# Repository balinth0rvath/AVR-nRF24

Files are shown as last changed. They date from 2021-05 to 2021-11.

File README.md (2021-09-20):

# RF Communication Mesh
### What is This?
A sensor network consisting a server running on a Pi and several environmental sensors based on AVR MCU's. These things are communicating each other via RF and the sensors are planned to work through a season with one charge of a 3.6V battery.  

---

### Code Structure
|Description|Module|
|---|---|
|Custom nRF24L01 driver in my forked Linux repo located in nRF24L01driver branch|https://github.com/balinth0rvath/linux/tree/nRF24L01driver|
|Server app and unit tests|https://github.com/balinth0rvath/AVR-nRF24/tree/master/server|
|HW related stuff (Schematics, gerber files etc...)|https://github.com/balinth0rvath/AVR-nRF24/tree/master/nRF24-design|
|Firmware of a sensor module|https://github.com/balinth0rvath/AVR-nRF24/tree/master/AVR-nRF24|

---

### Server UML
<p float="left">  
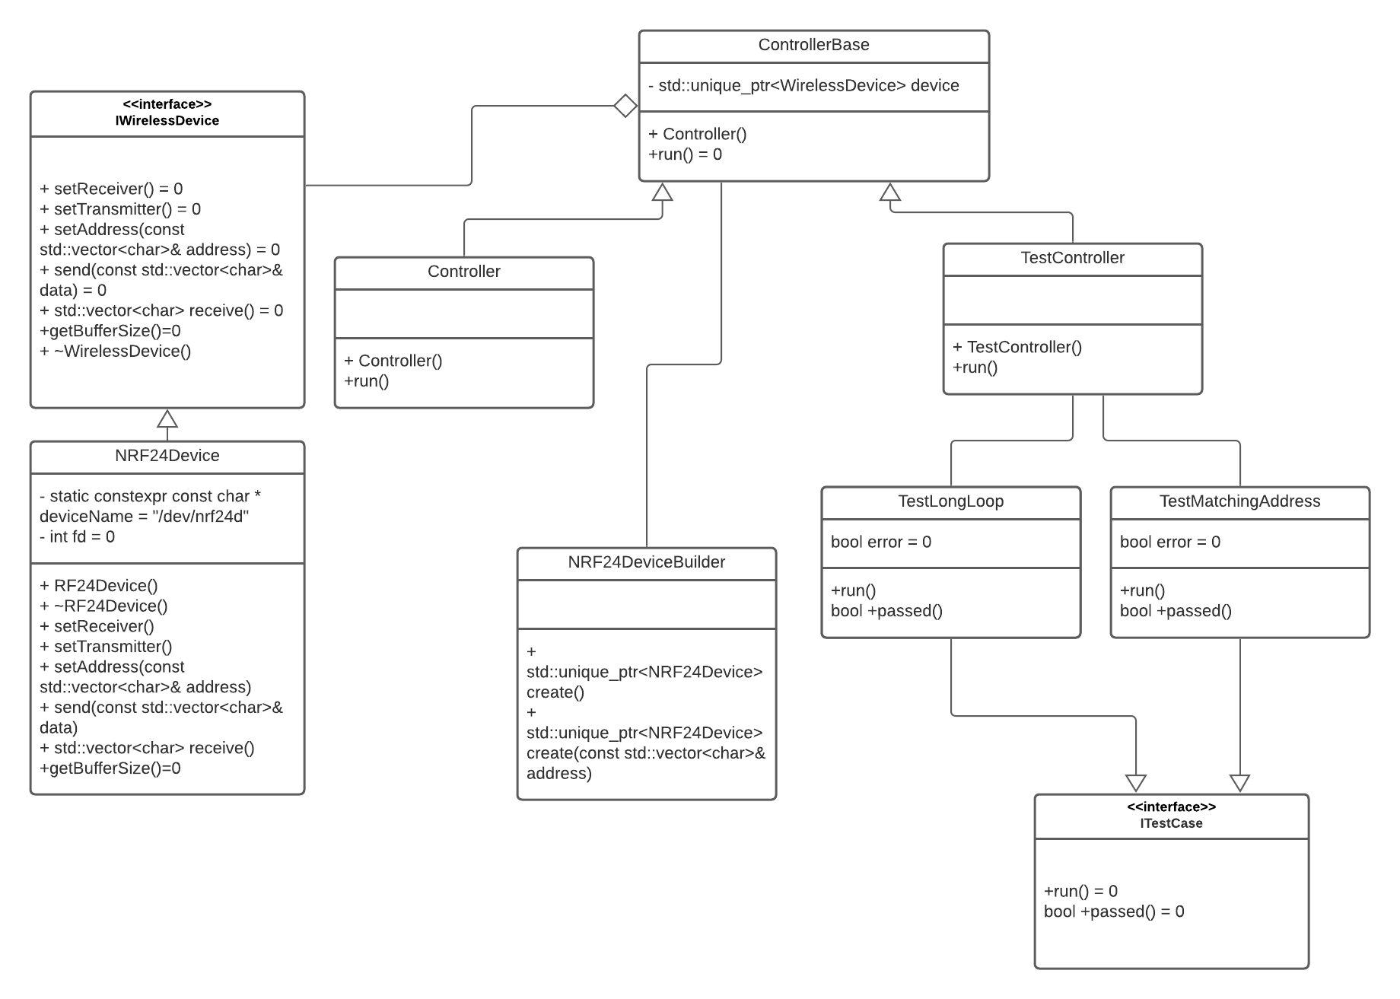
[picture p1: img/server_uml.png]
   
</p>

---

### Schematics
<p float="left">  
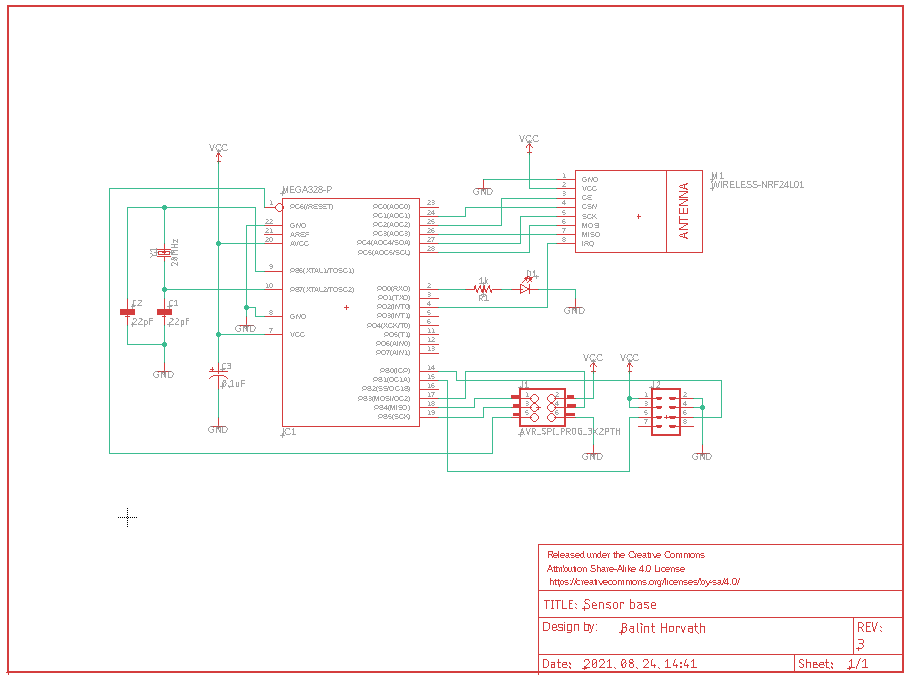
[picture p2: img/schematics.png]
   
</p>

---

### Current Dev Setup (Mid of September 2021)
<p float="left">  
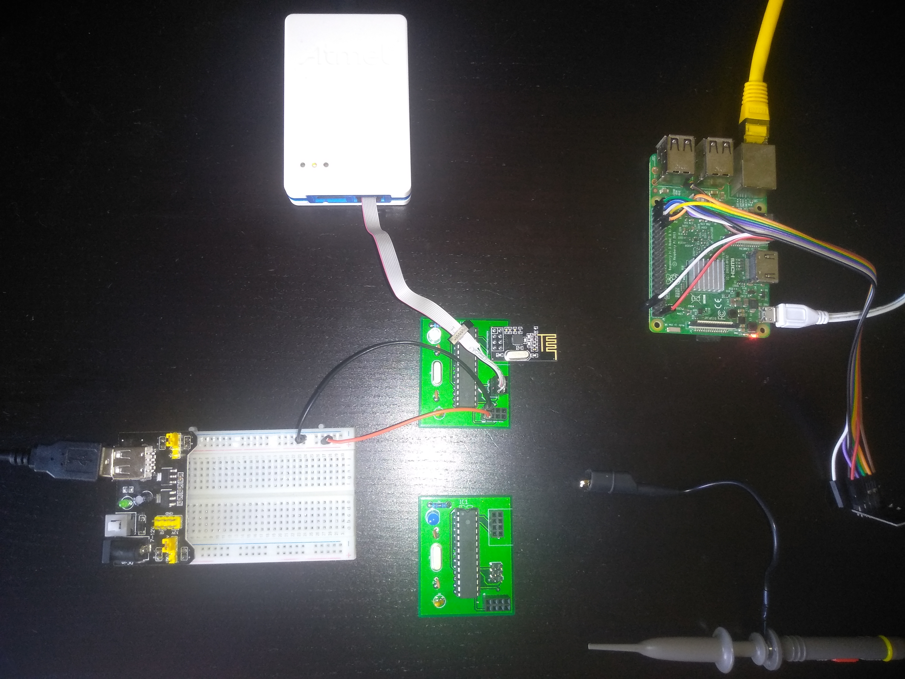
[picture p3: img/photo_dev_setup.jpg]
     
</p>

---

### Breadboard in Early Stage
<p float="left">  
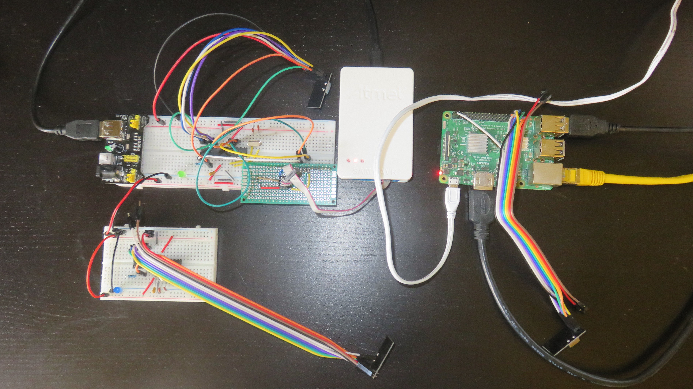
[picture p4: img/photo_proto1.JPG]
   
</p>

---

### First Prototypes without Sensors
<p float="left">  
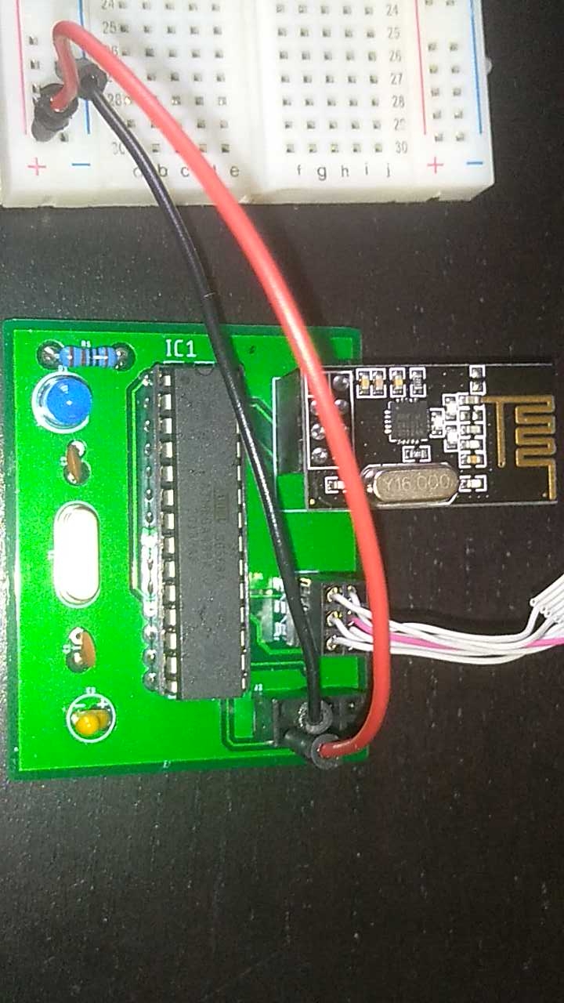
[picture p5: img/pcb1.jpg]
   
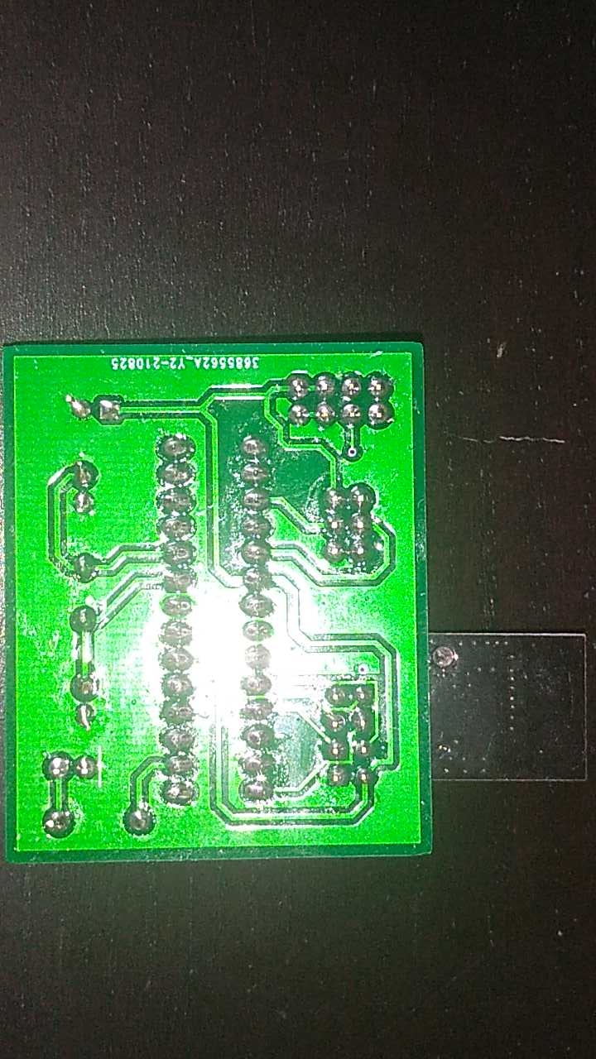
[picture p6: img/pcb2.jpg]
   
</p>

---

### Debug Screenshot, DS18B20 Sequence of Determining External Power Supply Mode
<p float="left">  
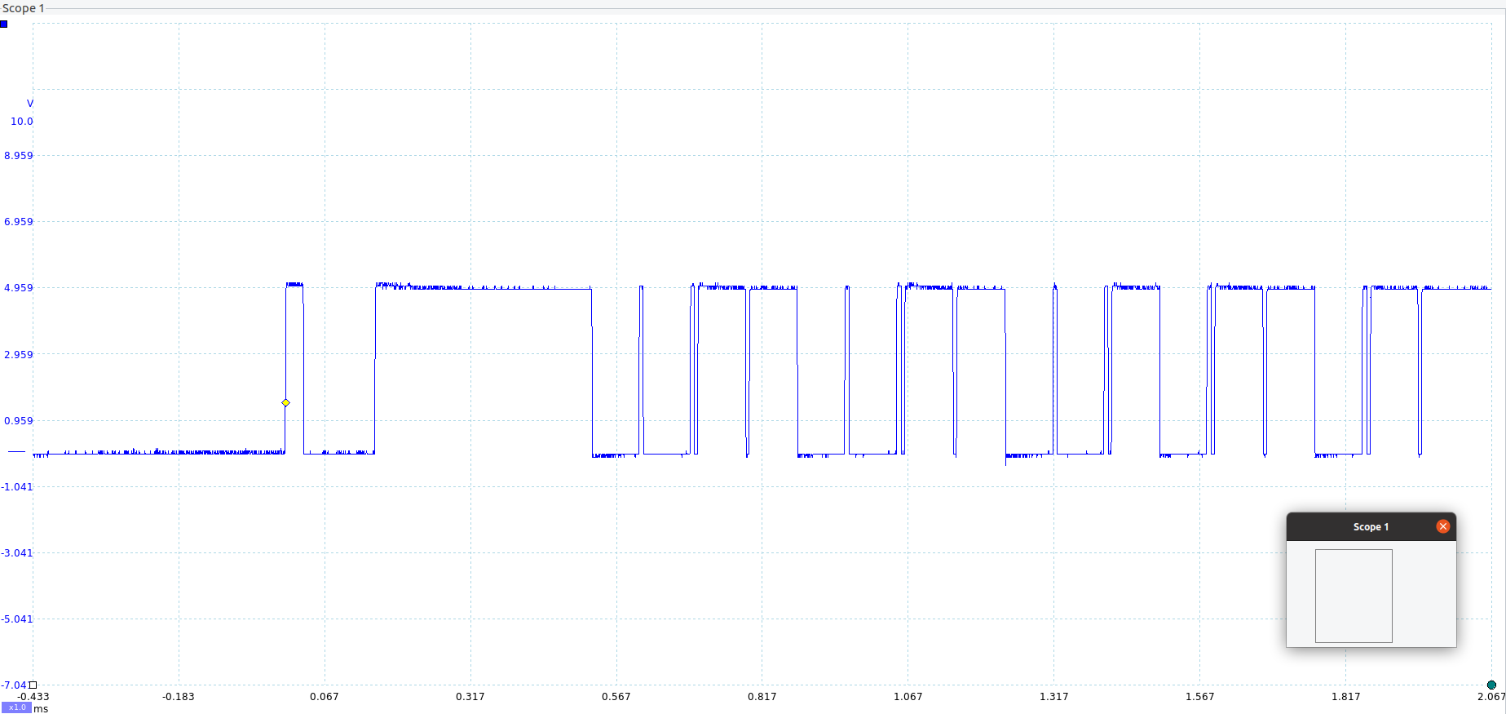
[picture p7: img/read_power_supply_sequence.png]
   
</p>

---
## Setup
### Init Yocto Build
```
$ mkdir rpi
$ cd rpi
$ git clone -b gatesgarth git://git.yoctoproject.org/poky.git
$ git clone -b gatesgarth git://git.openembedded.org/meta-openembedded
$ git clone -b gatesgarth git://git.openembedded.org/meta-raspberrypi
$ source poky/oe-init-build-env ./build
```
./build/conf/bblayers.conf
```
# POKY_BBLAYERS_CONF_VERSION is increased each time build/conf/bblayers.conf
# changes incompatibly
POKY_BBLAYERS_CONF_VERSION = "2" 

BBPATH = "${TOPDIR}"
BBFILES ?= ""

BBLAYERS ?= " \ 
  ~/yocto-builds/rpi/poky/meta \
  ~/yocto-builds/rpi/poky/meta-poky \
  ~/yocto-builds/rpi/poky/meta-yocto-bsp \
  ~/yocto-builds/rpi/meta-raspberrypi \
  ~/yocto-builds/rpi/meta-openembedded/meta-oe \
  ~/yocto-builds/rpi/meta-openembedded/meta-python \
  ~/yocto-builds/rpi/meta-openembedded/meta-networking \
  ~/yocto-builds/rpi/meta-openembedded/meta-multimedia \
  ~/yocto-builds/rpi/meta-openembedded/meta-filesystems \
  "
```

./build/conf/local.conf
```
...
MACHINE ??= "raspberrypi3"
...
DISTRO_FEATURES_append = "bluez5 bluetooth wifi systemd"
VIRTUAL-RUNTIME_init_manager = "systemd"
IMAGE_INSTALL_append = "crda iw bluez5 wpa-supplicant openssh"
```

### Create SD Card Image and SDK
```
$ cd rpi
$ . poky/oe-init-build-env
$ bitbake core-image-minimal
$ bitbake core-image-minimal -c populate_sdk
$ tmp/deploy/sdk/poky-glibc-x86_64-core-image-minimal-cortexa7t2hf-neon-vfpv4-raspberrypi3-toolchain-3.2.2.sh
```

### Install Packages
```
$ sudo apt-get install libssl-dev
```

### Build Kernel
```
$ cd <linux source root>
$ . /opt/poky/3.2.2/environment-setup-cortexa7t2hf-neon-vfpv4-poky-linux-gnueabi 
$ KERNEL=kernel7
$ make ARCH=arm CROSS_COMPILE=arm-poky-linux-gnueabi- bcm2709_defconfig
$ make ARCH=arm CROSS_COMPILE=arm-poky-linux-gnueabi- zImage modules dtbs
```

### Build Driver
```
$ cd <linux source root>
$ . /opt/poky/3.2.2/environment-setup-cortexa7t2hf-neon-vfpv4-poky-linux-gnueabi 
$ make ARCH=arm CROSS_COMPILE=arm-poky-linux-gnueabi- -C . M=drivers/char/nrf24/
$ scp nrf24.ko root@<IP of PI>:/home/root/.
```

### Server Setup
```
$ cd server
$ . /opt/poky/3.2.2/environment-setup-cortexa7t2hf-neon-vfpv4-poky-linux-gnueabi
$ make lib/libwireless.a
$ make
$ make test
$ scp server root@<IP of PI>:/home/root/.
$ scp test root@<IP of PI>:/home/root/.
```

### Server Init
```
$ insmod nrf24.ko
$ ./test
$ ./server
```

---

## Remote Debug Server
Target
```
$ gdbserver :1234 server
```
Host
```
$ arm-poky-linux-gnueabi-gdb server
(gdb) target remote <IP of PI>:1234
```
---

## Release Commits (Test Longloop)
A test named Test Longloop must pass in all release commits.
|Releas Date|Driver Branch and Commit Hash<br>Firmware and Design Branch and Commit Hash|
|----|---|
|20210517|linux@nRF24L01driver:8a4c0cdf7803df328cc4730b5077f52fee5dc932<br>AVR-nRF24@master:3eb939d17d8ff22d65403e109d810f7f85f86c85|
|20210523|linux@nRF24L01driver:8a4c0cdf7803df328cc4730b5077f52fee5dc932<br>AVR-nRF24@master:7b25dc61fc849677e8bb6358456cee5dc74c7301|
|20210531|linux@nRF24L01driver:7c86b9ca6b2d7ad1549c76c9caeeb97bab567bfb<br>AVR-nRF24@master:dd0c3b836620fbdc131a8c8d285148fa6ca5f2e6|
|20210820|inux@nRF24L01driver:7c86b9ca6b2d7ad1549c76c9caeeb97bab567bfb<br>AVR-nRF24@master:85c61a1c3e08124cf29ecca4751b73a7c155e9e8|
|20210909|linux@nRF24L01driver:f5a8eb844164f856415a3b459346a1253c0f87ff<br>AVR-nRF24@master:ca4479ed1e2c967fedf4eaf3a40d907f1cda15d0|
|20210919|linux@nRF24L01driver:f5a8eb844164f856415a3b459346a1253c0f87ff<br>AVR-nRF24@master:d2804b9a1e1fc83868c6ceb204d5eec31b9cb42f|

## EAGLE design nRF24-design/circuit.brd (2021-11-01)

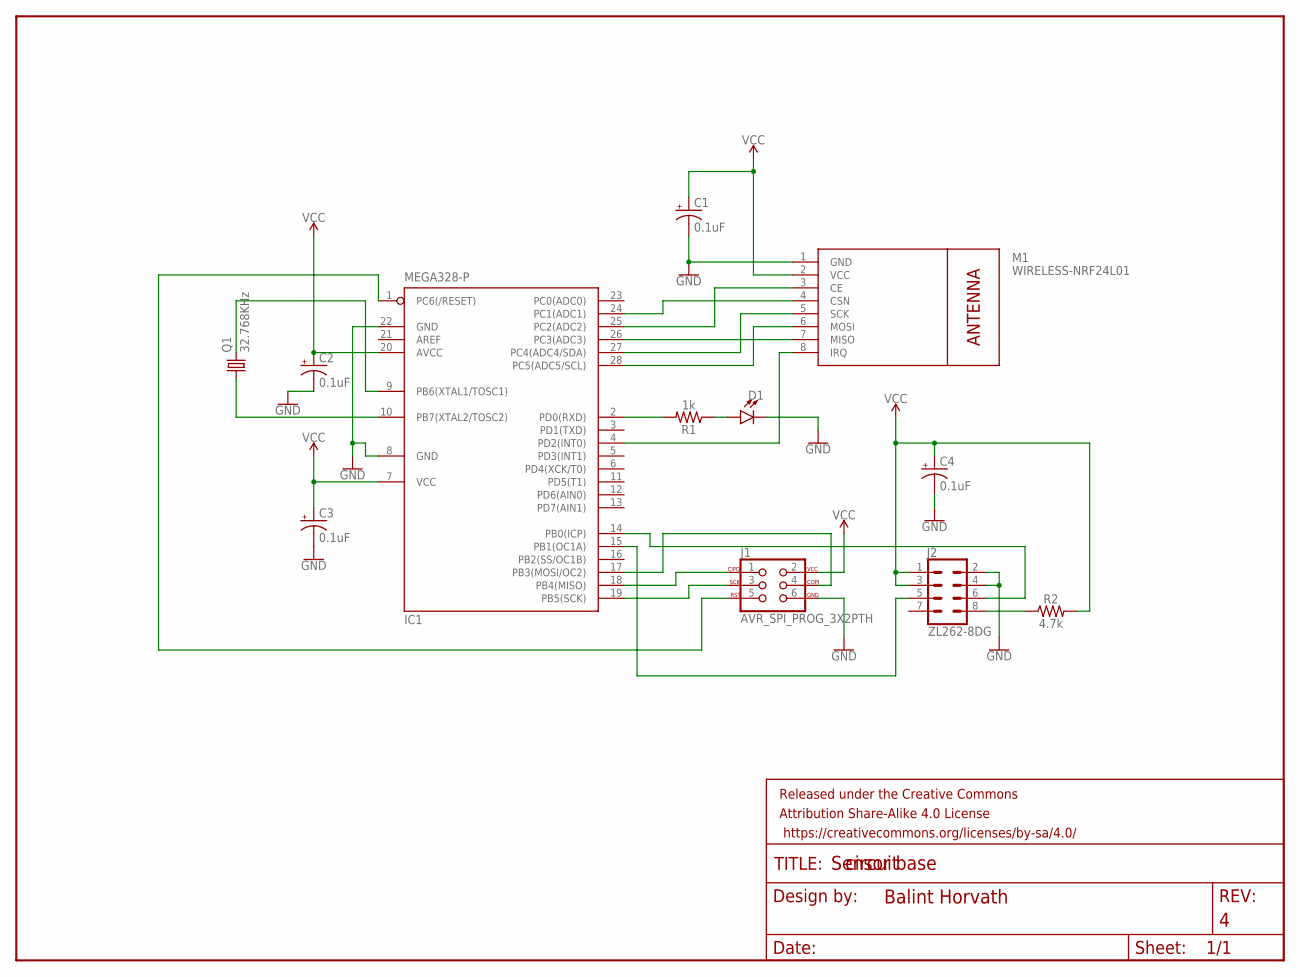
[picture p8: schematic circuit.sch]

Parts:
C1, C2, C3, C4: 0.1uF; CPOL-RADIAL-2.5MM-5MM
D1: LED5MM; LED_5MM
FRAME1: FRAME-LETTER; CREATIVE_COMMONS
IC1: MEGA328-P; DIL28-3
J1: AVR_SPI_PROG_3X2PTH; 2X3
J2: ZL262-8DG; 2X4
M1: WIRELESS-NRF24L01
Q1: 32.768KHz; TC26V
R1: 1k; AXIAL-0.3
R2: 4.7k; AXIAL-0.3

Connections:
GND: C1.2 (-), C2.2 (-), C3.2 (-), C4.2 (-), D1.K (C), IC1.8 (GND), IC1.22 (GND), J1.6, J2.2, J2.4, M1.1 (GND)
unnamed: IC1.9 (PB6(XTAL1/TOSC1)), Q1.2
unnamed: IC1.10 (PB7(XTAL2/TOSC2)), Q1.1
unnamed: IC1.2 (PD0(RXD)), R1.P$2 (2)
unnamed: D1.A, R1.P$1 (1)
unnamed: IC1.27 (PC4(ADC4/SDA)), M1.5 (SCK)
unnamed: IC1.4 (PD2(INT0)), M1.8 (IRQ)
unnamed: IC1.24 (PC1(ADC1)), M1.4 (CSN)
unnamed: IC1.26 (PC3(ADC3)), M1.7 (MISO)
unnamed: IC1.25 (PC2(ADC2)), M1.3 (CE)
unnamed: IC1.28 (PC5(ADC5/SCL)), M1.6 (MOSI)
unnamed: IC1.19 (PB5(SCK)), J1.3
unnamed: IC1.18 (PB4(MISO)), J1.1
unnamed: IC1.1 (PC6(/RESET)), J1.5
unnamed: IC1.17 (PB3(MOSI/OC2)), J1.4
unnamed: IC1.15 (PB1(OC1A)), J2.5
unnamed: J2.8, R2.P$1 (1)
unnamed: IC1.14 (PB0(ICP)), J2.6
VCC: C1.1 (+), C2.1 (+), C3.1 (+), C4.1 (+), IC1.7 (VCC), IC1.20 (AVCC), J1.2, J2.1, J2.3, M1.2 (VCC), R2.P$2 (2)

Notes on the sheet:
Sensor base

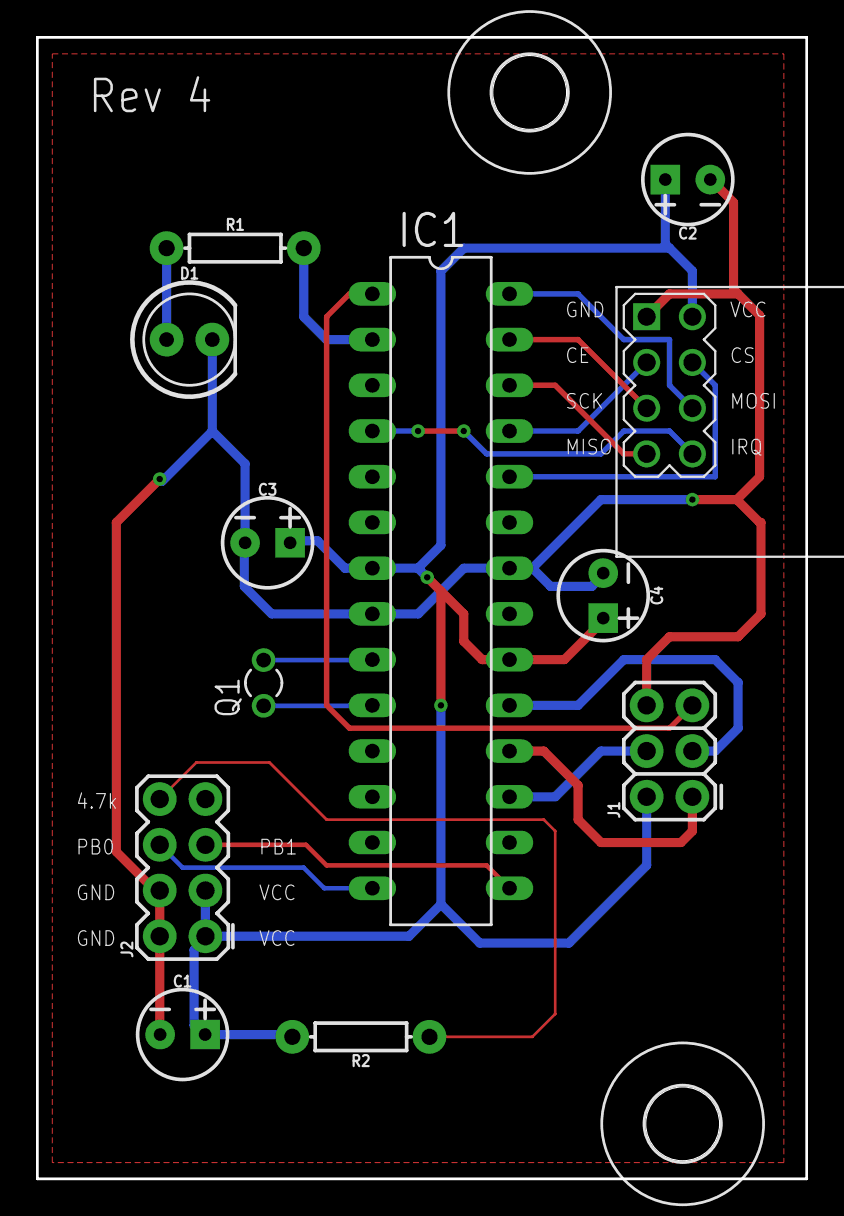
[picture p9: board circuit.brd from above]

Board: 2 copper layers, 42.7 x 63.4 mm, 15 parts (0 on the bottom side), 19 nets.

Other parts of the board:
U$1, U$2: 4,1

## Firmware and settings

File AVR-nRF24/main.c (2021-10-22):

/*
 * AVR-nRF24.c
 *
 * Created: 4/30/2021 3:04:23 PM
 *
 * author: balinth0rvath 
 */ 

 #define INIT_SETUP
 #undef TEST_BLINK 
 #undef TEST_ONE_PACKET 
 #undef TEST_LONGLOOP
 #undef TEST_SENSOR
 #undef TEST_SLEEP
 #define TEST_TIMER

#include "common.h"
#include <avr/io.h>
#include <util/delay.h>
#include <avr/interrupt.h>
#include <avr/sleep.h>
#include "nrf24.h"
#include "ds18b20.h"

void send_response(char* payload);

void send_response_with_head(void)
{					
	char payload[4] = {};
	nrf24_payload_buffer_item_t p;
	nrf24_get_buffer_head(&p);
	payload[0] = p.id;
	payload[1] = p.source_address;
	payload[2] = p.value;
	payload[3] = p.aux;
	send_response(payload);
	
}

void send_response_with_temperature(void)
{  
  char payload[4] = {};
  payload[0] = 0;
  payload[1] = 0;
  payload[2] = ds18b20_read_temperature() >> 4;
  payload[3] = 0;
  send_response(payload);
  
}

void send_response(char* payload)
{
  uint8_t status;
  nrf24_transmit_packet(payload, &status);
  _delay_ms(100);
  
  nrf24_transmit_packet(payload, &status);
  _delay_ms(100);
  
}

void send_dummy_packet(void)
{	
	uint8_t status;			
	char payload[4] = {};
	payload[0] = 54;
	payload[1] = 55;
	payload[2] = 53;
	payload[3] = 54;
	nrf24_transmit_packet(payload, &status);	
	_delay_ms(100);	
		
	nrf24_transmit_packet(payload, &status);	
	_delay_ms(100);	
	
}

static void blink(uint8_t number, uint8_t fast)
{
	int i=0;
	for(i=0;i<number;i++)
	{
		PORTD ^= (1 << PD0);
		if (fast)
    {
			_delay_ms(50);		
    }
		else
    {
			_delay_ms(300);		
    }
	}	
}

int main(void)
{	
  volatile int ret;	
	DDRD|=( 1 << PD0);	
  PORTD &= ~(1 << PD0);

#ifdef INIT_SETUP
	//blink(2,0);
	nrf24_init(0);	

	ret = nrf24_check_device();	
  
	if (ret!=0)
	{
		blink(10,1);
	}
	
	uint8_t address[5] = {0x10, 0x20, 0x30, 0x40, 0x50};
	
	nrf24_set_rx_address_p0(address);
	nrf24_set_tx_address(address);	
	nrf24_set_receiver();	
	
	EICRA &= ~(1 << ISC00 | 1 << ISC01);
	EIMSK |= (1 << INT0);
	sei();	
#endif // INIT_SETUP	

#ifdef TEST_BLINK
  _delay_ms(1000);	
  int i = 20;
  while(i--)
  {
    PORTD ^= (1 << PD0);
    _delay_ms(500);	
  }
  while(1);
#endif // TEST_BLINK

#ifdef TEST_ONE_PACKET
	nrf24_set_transmitter();
	_delay_ms(10);
	send_dummy_packet();
	_delay_ms(10);
	while(1);
	
#endif //ONE_PACKET

#ifdef TEST_LONGLOOP
	nrf24_set_receiver();	
	while(1)	
	{		
		_delay_ms(10);
		if (nrf4_message_received())			
		{			      
			nrf24_set_transmitter();
			send_response_with_head();
			
			blink(8,1);
			nrf24_set_receiver();	
		}
	}	
#endif //TEST_LONGLOOP

#ifdef TEST_SENSOR

  ds18b20_init_driver();
  nrf24_set_receiver();
  while(1)
  {
    _delay_ms(10);
    if (nrf4_message_received())
    {
      nrf24_set_transmitter();
      send_response_with_temperature();
      
      blink(8,1);
      nrf24_set_receiver();
    }
  }  
#endif // TEST_SENSOR

#ifdef TEST_SLEEP
  sleep_enable();
  set_sleep_mode(SLEEP_MODE_PWR_DOWN);
  ADCSRA = 0;

  sleep_cpu();
  while(1)
  {
    _delay_ms(1000);
  }
#endif // TEST_SLEEP
  
#ifdef TEST_TIMER
  DDRB|=1 << PB0;
  PORTB &= ~(1 << PB0); 

  // Disable timer counter 2 interrupts by clearing OCIE2x and TOIE2
  TIMSK2&=~(1 << OCIE2B | 1 << OCIE2A | 1 << TOIE2);
  // Select external crystal
  ASSR|=(1 << AS2);

  // Write new values to TCNT2 OCR2x and TCCR2x
  TCNT2 = 0;
  TCCR2B|= (1 << CS20) | (1 << CS21) | (1 << CS22);  

  // Wait for TCN2xUB, OCR2xUB and TCR2xUB
  while(ASSR & (1<<TCN2UB | 1<<TCR2BUB));
  // Clear the timer counter2 interrupt flags
  TIFR2|=(1 << TOV2) | (1 << OCF2A) | (1 << OCF2B); 
  // Enable interrupts
  TIMSK2|=(1 << TOIE2);
  sei();
  sleep_enable();
  set_sleep_mode(SLEEP_MODE_PWR_SAVE);
  ADCSRA = 0;
  
  while(1)
  {
    sleep_cpu();      
    for(int i=0;i<1255;++i)
    {
      PORTB ^= (1 << PB0);
    }    
  }
  
  
#endif // TEST_SLEEP

}


ISR (INT0_vect)
{	
	volatile uint8_t ret = nrf24_get_status();	
	if (ret & 0x40)
	{
		nrf24_receive_irq();
	} else if (ret & 0x20)
	{
		nrf24_transmit_irq();			
	}	
}

ISR (TIMER2_OVF_vect)
{
  
}

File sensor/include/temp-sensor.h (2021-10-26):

/*
 * temp_sensor.h
 *
 * Created: 10/26/2021 5:43:42 PM
 *  Author: balinth0horvath
 */ 


#ifndef TEMPSENSOR_H_
#define TEMPSENSOR_H_

#include <avr/io.h>

// Data Port
#define DS18B20_DDR                             DDRB
#define DS18B20_PORT                            PORTB
#define DS18B20_PIN                             PINB

// Pin settings
#define DS18B20_DQ                              PB0

// DS18B20 commands
#define DS18B20_CMD_SEARCH_ROM                  0xf0
#define DS18B20_CMD_READ_ROM                    0x33
#define DS18B20_CMD_MATCH_ROM                   0x55
#define DS18B20_CMD_SKIP_ROM                    0xcc
#define DS18B20_CMD_ALARM_SEARCH                0xec
#define DS18B20_CMD_CONVERT_T                   0x44
#define DS18B20_CMD_READ_SCRATCHPAD             0xbe
#define DS18B20_CMD_WRITE_SCRATCHPAD            0x4e
#define DS18B20_CMD_COPY_SCRATCHPAD             0x48
#define DS18B20_CMD_RECALL_E                    0xb8
#define DS18B20_CMD_READ_POWER_SUPPLY           0xb4


// DS18B20 registers
#define DS18B20_REG_TEMP_LSB                    0x00
#define DS18B20_REG_TEMP_MSB                    0x01
#define DS18B20_REG_TH                          0x02
#define DS18B20_REG_TL                          0x03
#define DS18B20_REG_CONFIG                      0x04
#define DS18B20_REG_CRC                         0x08

// DS18B20 timings
// Init procedure
#define DS18B20_TM_RESET_PULSE_US               500
#define DS18B20_TM_WAIT_RESET_US                15
#define DS18B20_TM_PRESENCE_SLICE_US            20              
#define DS18B20_TM_PRESENCE_COUNT               15
#define DS18B20_TM_WAIT_PRESENCE_US             200

// Time slot timings
#define DS18B20_TM_WRITE_FULL_SLOT_LENGTH_US    80
#define DS18B20_TM_WRITE_1_SLOT_LENGTH_US       5 
#define DS18B20_TM_READ_FULL_SLOT_LENGTH_US     80
#define DS18B20_TM_READ_INIT_LENGTH_US          5
#define DS18B20_TM_READ_SAMPLE_AFTER_INIT_US    10
#define DS18B20_TM_RELEASE_SLOT_US              5

#define DS18B20_MAX_CONVERSION_TIME_MS          750

class TempSensor {
public:
  void initDriver();
  void setResolution(unsigned char resolution);
  int readTemperature();
  int isExternalPowerSupply();
private:
  int initProc();
  int skipRom();
  void writeStratchpad(unsigned char* data);
  void readStratchpad(unsigned char* data);
  void copyStratchpad();
  void recallE();
  int readPowerSupply();
  void convertT();
  void writeByte(unsigned char byte);
  unsigned char readByte();
  int waitDQ();
  void writeSlot(unsigned char bit);
  unsigned char readSlot();
  void release();
  void pullLow();
};


#endif /* TEMP-SENSOR_H_ */

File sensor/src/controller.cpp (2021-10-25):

/*
 * controller.cpp
 *
 * Created: 10/23/2021 3:57:13 PM
 *  Author: balinth0horvath
 */ 

 #include "controller.h"
 #include <avr/io.h>
 #include <avr/interrupt.h>
 #include "common.h"
 #include <util/delay.h>
 #include <avr/io.h>

 Controller::Controller()
 {
  unsigned char address[5]={0x10,0x20,0x30,0x40,0x50};
  wirelessDevice.init(false);
  wirelessDevice.setTXAddress(address);
  wirelessDevice.setRxAddressP0(address);

  if(!wirelessDevice.checkDevice())
  {
    controlLight.blink(100);
  }
  wirelessDevice.setReceiver();

  initIRQ();       
 }

 void Controller::runLongLoop()
 {
   while(1)
   {
     _delay_ms(10);
     if (wirelessDevice.isMessageReceived())
     {
       wirelessDevice.setTransmitter();
       sendResponseWithHead();      
       controlLight.blink(8);  
       wirelessDevice.setReceiver();
     }
   }
 }

 void Controller::sendResponse(char* payload)
 {
   unsigned char status;
   wirelessDevice.transmitPacket(payload, &status);
   _delay_ms(100);   
   wirelessDevice.transmitPacket(payload, &status);
   _delay_ms(100);   
 }

 void Controller::sendResponseWithHead()
 {
   char payload[4] = {};
   PayloadBufferItem p;
   wirelessDevice.getBufferHead(&p);
   payload[0] = p.id;
   payload[1] = p.sourceAddress;
   payload[2] = p.value;
   payload[3] = p.aux;
   sendResponse(payload);
 }

void Controller::initIRQ()
{
  EICRA &= ~(1 << ISC00 | 1 << ISC01);
  EIMSK |= (1 << INT0);
  sei();
}

 ControlLight::ControlLight()
 {
  DDRD|=( 1 << PD0); 
  PORTD &= ~(1 << PD0);
  PORTD |= 1 << PD0;
  _delay_ms(500);
  PORTD &= ~(1 << PD0);
 }

 void ControlLight::blink(unsigned char number)
 {
 int i=0;
	for(i=0;i<number;i++)
	{
		PORTD ^= (1 << PD0);
		_delay_ms(50);		  
  }  
 }

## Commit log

2021-04-30 nrf24: Implement basic bitbang driver functions
2021-05-01 Fix bugs in nrf24 init
    [main.c, nrf24.c, nrf24.h]
2021-05-01 Fix bug with MISO pin
    [nrf24.c]
2021-05-03 Refactor code. Replace 16bit variables with 8bit, if possibble
    [nrf24.c, nrf24.h]
2021-05-07 Implement interrupt handling
2021-05-07 Implement interrupt handling in tx mode too
2021-05-07 Prepare switching between built in SPI and bitbang SPI
2021-05-08 Use HW SPI
2021-05-08 Check HW SPI receiver. Put half cycle wait into bb
2021-05-19 Prepare test framework
2021-05-22 Implement structure of test cases. Implement open driver test case
2021-05-23 Upload schematics
2021-05-23 Setup indicator led. Set, get RXP0, TX addresses
2021-05-30 Use LED blinking for feedback
2021-08-15 Add eagle files
    [circuit.sch]
2021-08-17 Finish schematics. Create board files. Create Gerber files
    [circuit.brd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]
2021-08-17 Fix design. Add image of schematics
    [circuit.brd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]
2021-08-17 Create Gerber files
    [circuit.brd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]
2021-08-17 Create Gerber files for jlcpcb
    [circuit.GBL, circuit.GBO, circuit.GBP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]
2021-08-19 server: Create device interface
2021-08-20 server: nrf24 device impl skeleton
2021-08-20 server: create device builder
2021-08-23 design: Fix errors (missing power and cipo connections)
    [circuit.brd, circuit.sch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]
2021-08-24 design: add power connectors. Add sensor connectors
    [circuit.brd, circuit.sch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]
2021-08-30 design: Upload photo of PCB
2021-08-30 Update readme regarding the pictures of PCB
2021-08-31 mcu: Switch to ATMEGA 48PU
2021-08-31 mcu: Create header of DS18B20 temperature sensor driver
2021-09-01 mcu: Implement commands and full read temperature
2021-09-07 mcu: Fix ds18b20 driver timings and sequences
    [ds18b20.h]
2021-09-08 mcu: Implement DS18B20 read power supply
2021-09-09 test: temperature sensor test
2021-09-09 mcu: Setup temperature sensor test
2021-09-16 mcu: Implement nRF24 power down
2021-09-16 server: Refactor wireless interface
2021-09-19 mcu: Add photo of current setup
2021-09-19 common: Sync readme with current status
2021-10-21 mcu: Setup sleep block. Use internal oscillator from now
    [main.c]
2021-10-21 mcu: Create basic timer function
2021-10-22 mcu: Implement periodic POWER_SAVE using external 32.768KHz crystal. Switch back to 328
2021-10-25 mcu: Rewrite nrf24 driver and longloop test in c++
2021-10-26 mcu: Rewrite ds18b20 driver in c++
2021-11-01 design: Align dimensions to box. Add more decoupling capacitors and labels
    [circuit.brd, circuit.sch]

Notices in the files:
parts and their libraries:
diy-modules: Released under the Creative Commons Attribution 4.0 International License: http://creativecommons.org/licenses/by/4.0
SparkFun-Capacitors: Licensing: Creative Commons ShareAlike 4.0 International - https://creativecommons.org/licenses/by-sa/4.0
